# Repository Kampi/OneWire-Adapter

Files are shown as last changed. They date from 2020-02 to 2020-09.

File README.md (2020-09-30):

# 1-Wire Adapter

## Table of Contents

- [1-Wire Adapter](#1-wire-adapter)
  - [Table of Contents](#table-of-contents)
  - [About](#about)
  - [History](#history)
  - [Maintainer](#maintainer)

## About

Small extension board to use a UART as a 1-Wire interface.

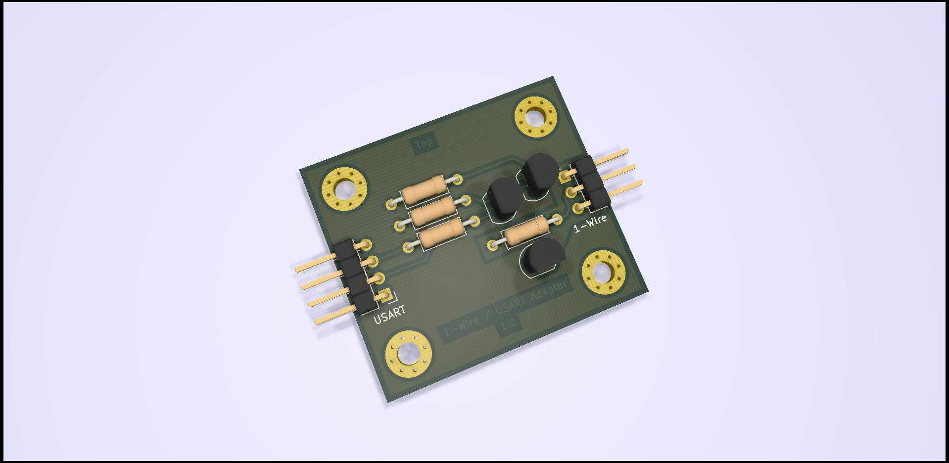
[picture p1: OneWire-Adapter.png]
Overview


## History

| **Version**  | **Description** | **Date** |
|:---:|:---:|:---:|
| 1.0 | First hardware release | 30.09.2020 |

## Maintainer

- [Daniel Kampert](mailto:DanielKampert@kampis-elektroecke.de)

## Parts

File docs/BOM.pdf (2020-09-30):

## Stückliste Bill of Materials

Nummer Number | Bezeichnung Description | Wert Value | Gehäuse Case | Hersteller Manufacturer | Herstellerbezeichnung Manufacturer's designation | Lieferant Distributor | Bestellnummer Order number | Anzahl Quantity
R1, R4 | Resistor | 10k | R_Axial_DIN0207_L6.3mm_D 2.5mm_P10.16mm_Horizont | Yageo | MFR-25FBF52-10K | | | 2
R2 | Resistor | 100k | R_Axial_DIN0207_L6.3mm_D 2.5mm_P10.16mm_Horizont | Yageo | MFR-25FBF52-100K | | | 1
R3 | Resistor | 4,7k | R_Axial_DIN0207_L6.3mm_D 2.5mm_P10.16mm_Horizont | Yageo | MFR-25FBF52-4K7 | | | 1
T1, T2 | 0.1A Ic, 45V Vce, Small Signal NPN Transistor, TO-92 | BC547 | TO-92_Inline | ON Semiconductor / Fairchild | BC547ATA | | | 2
T3 | 0.5A Id, 60V Vds, N-Channel MOSFET, TO-92 | BS170 | TO-92_Inline | ON Semiconductor / Fairchild | BS170 | | | 1
X1 | Generic connector, single row, 01x04 | USART | PinHeader_1x04_P2.54mm_ Horizontal | Harwin | M20-9960445 | | | 1
X2 | Generic connector, single row, 01x03 | 1-Wire | PinHeader_1x03_P2.54mm_ Horizontal | Harwin | M20-9750346 | | | 1

Legende / Legend:

Nicht bestückt | Not assembled
Durchsteckmontage | Through-Hole technology

30.09.2020

1.00

Bezeichnung / Name : 1-Wire / USART Adapter

Seite 1 von 2

## Technische Spezifikationen Technical Specifications

30.09.2020

1.00

Bezeichnung Description | Spezifikation Specification
Abmaße Dimensions | 40 x 35 mm
Standard Standard | IPC-A-610 E Class 2 oder höher IPC-A-610 E Class 2 or higher
Basismaterial Base material | 1,5 mm FR4, 35 µmCu
Stopplack Soldermask | Beidseitig Grün Both sides green
Bestückungsdruck Silkscreen | Keiner None
Oberfläche Surface | Chemisch Nickel-Gold Chemical nickel-gold
Isolierlack Insulation varnish | Nein No
Min. Bohrdurchmesser Min. drill-end diameter | 0,2 mm
Min. Leiterbahnbreite Min track size | 0,1 mm
Min. Leiterbahnabstand Min track distance | 0,2 mm
Kantenmetallisierung Sideplating | Nein No
Freistellung Vias Clearance vias | Bohrlochdurchmesser + max. 0,15 mm gemäß ZVEI Drill hole + max. 0,15 mm regarding ZVEI
Kontur Contour | Gefräst oder geritzt gemäß DIN ISO 2768 mittel Milled or scored according DIN ISO 2768 medium

Bezeichnung / Name: 1-Wire / USART Adapter

2 / 2

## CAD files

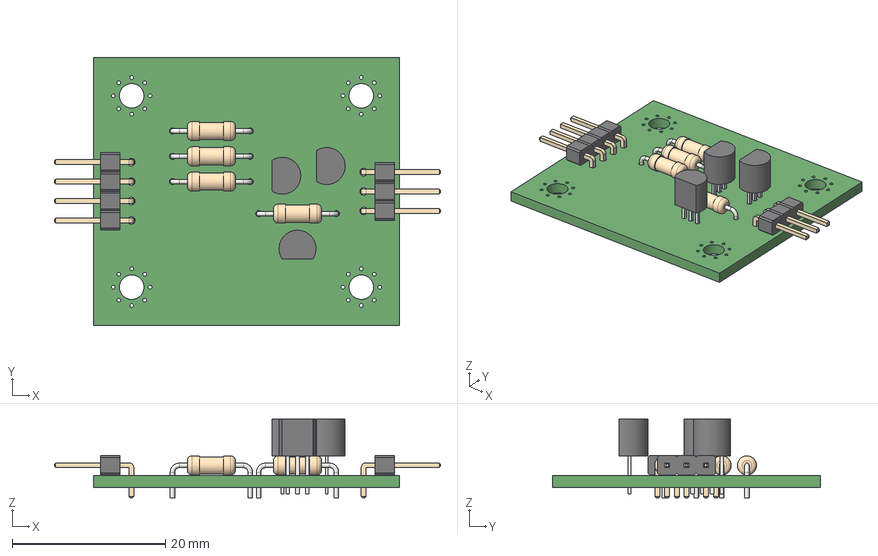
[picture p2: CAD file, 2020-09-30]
drawings/OneWire_Adapter.step
50.4 x 35.0 x 10.3 mm

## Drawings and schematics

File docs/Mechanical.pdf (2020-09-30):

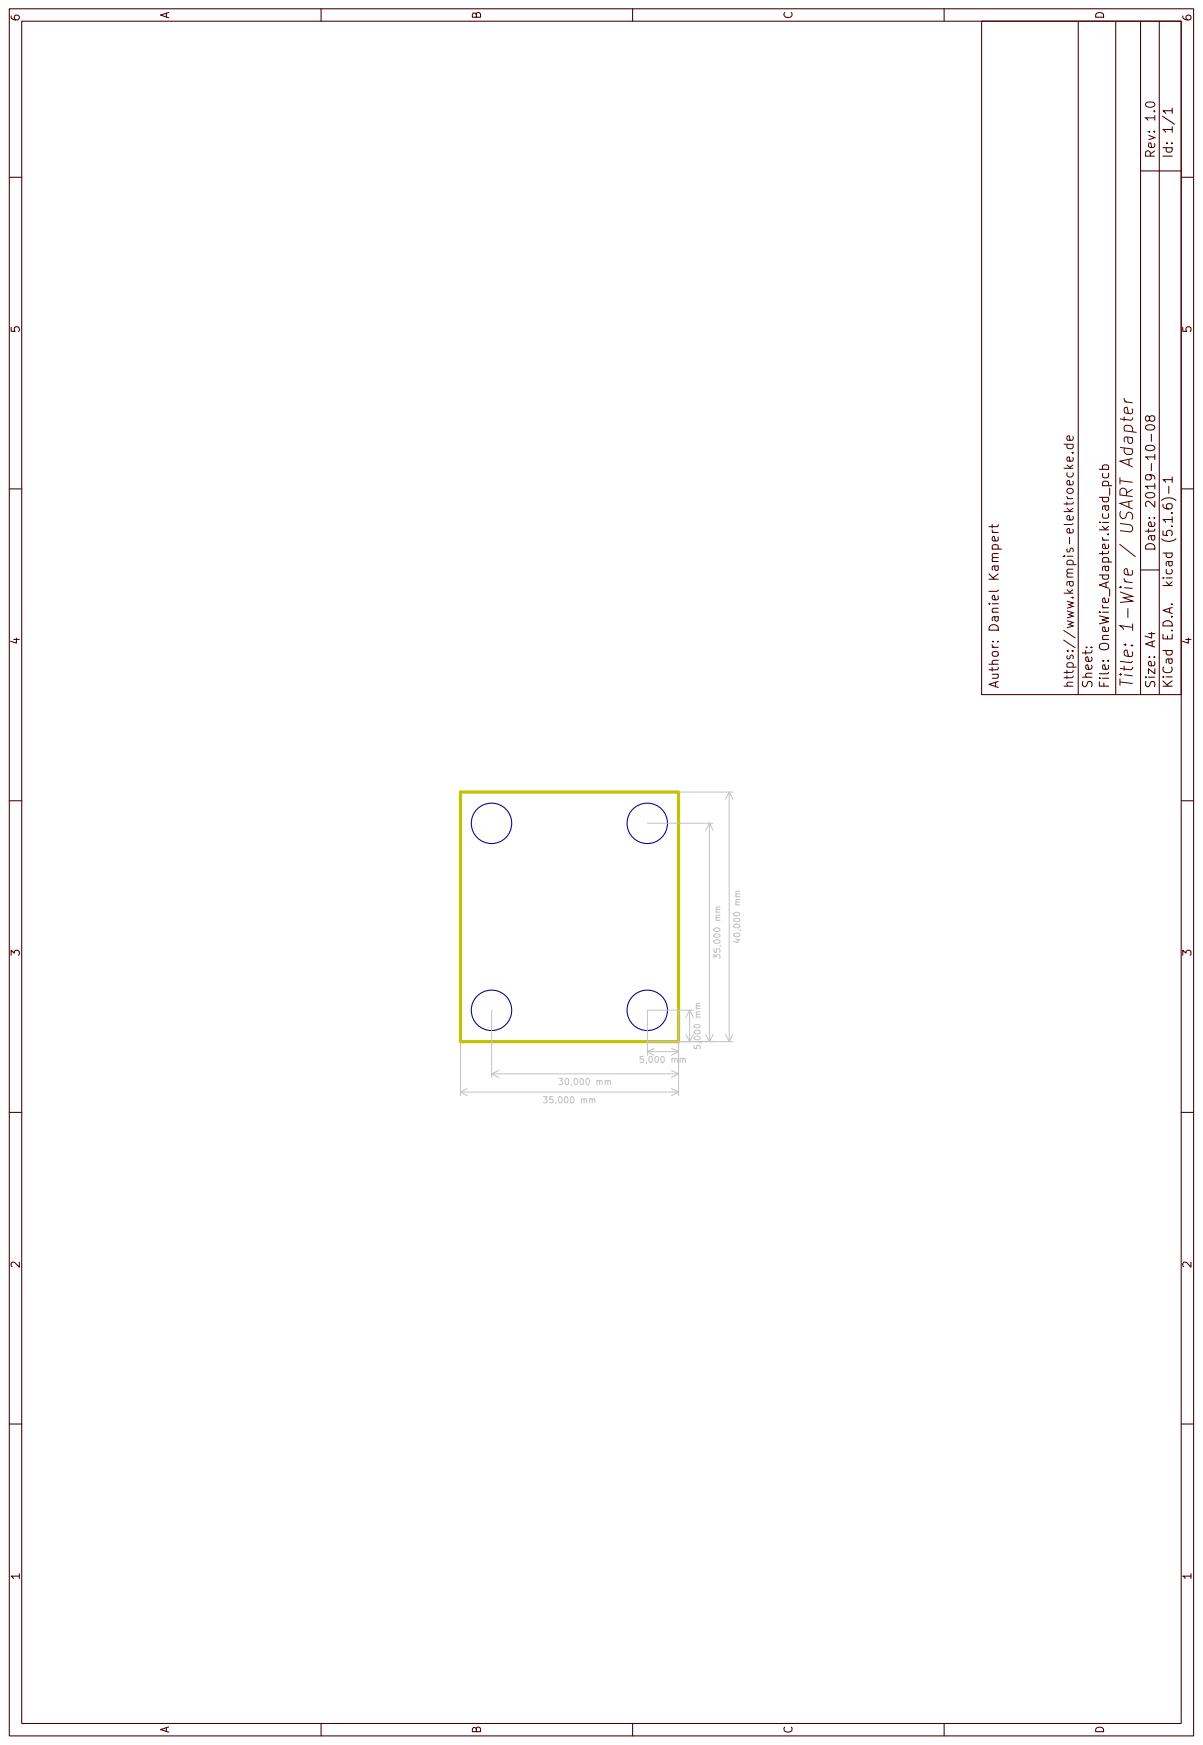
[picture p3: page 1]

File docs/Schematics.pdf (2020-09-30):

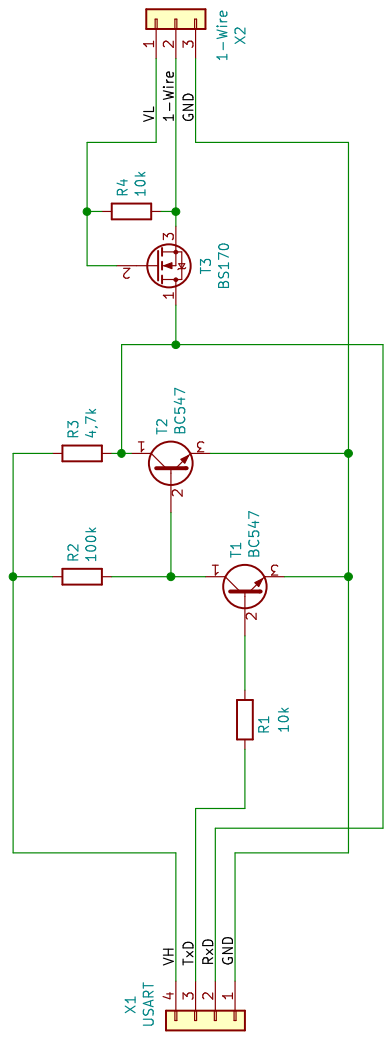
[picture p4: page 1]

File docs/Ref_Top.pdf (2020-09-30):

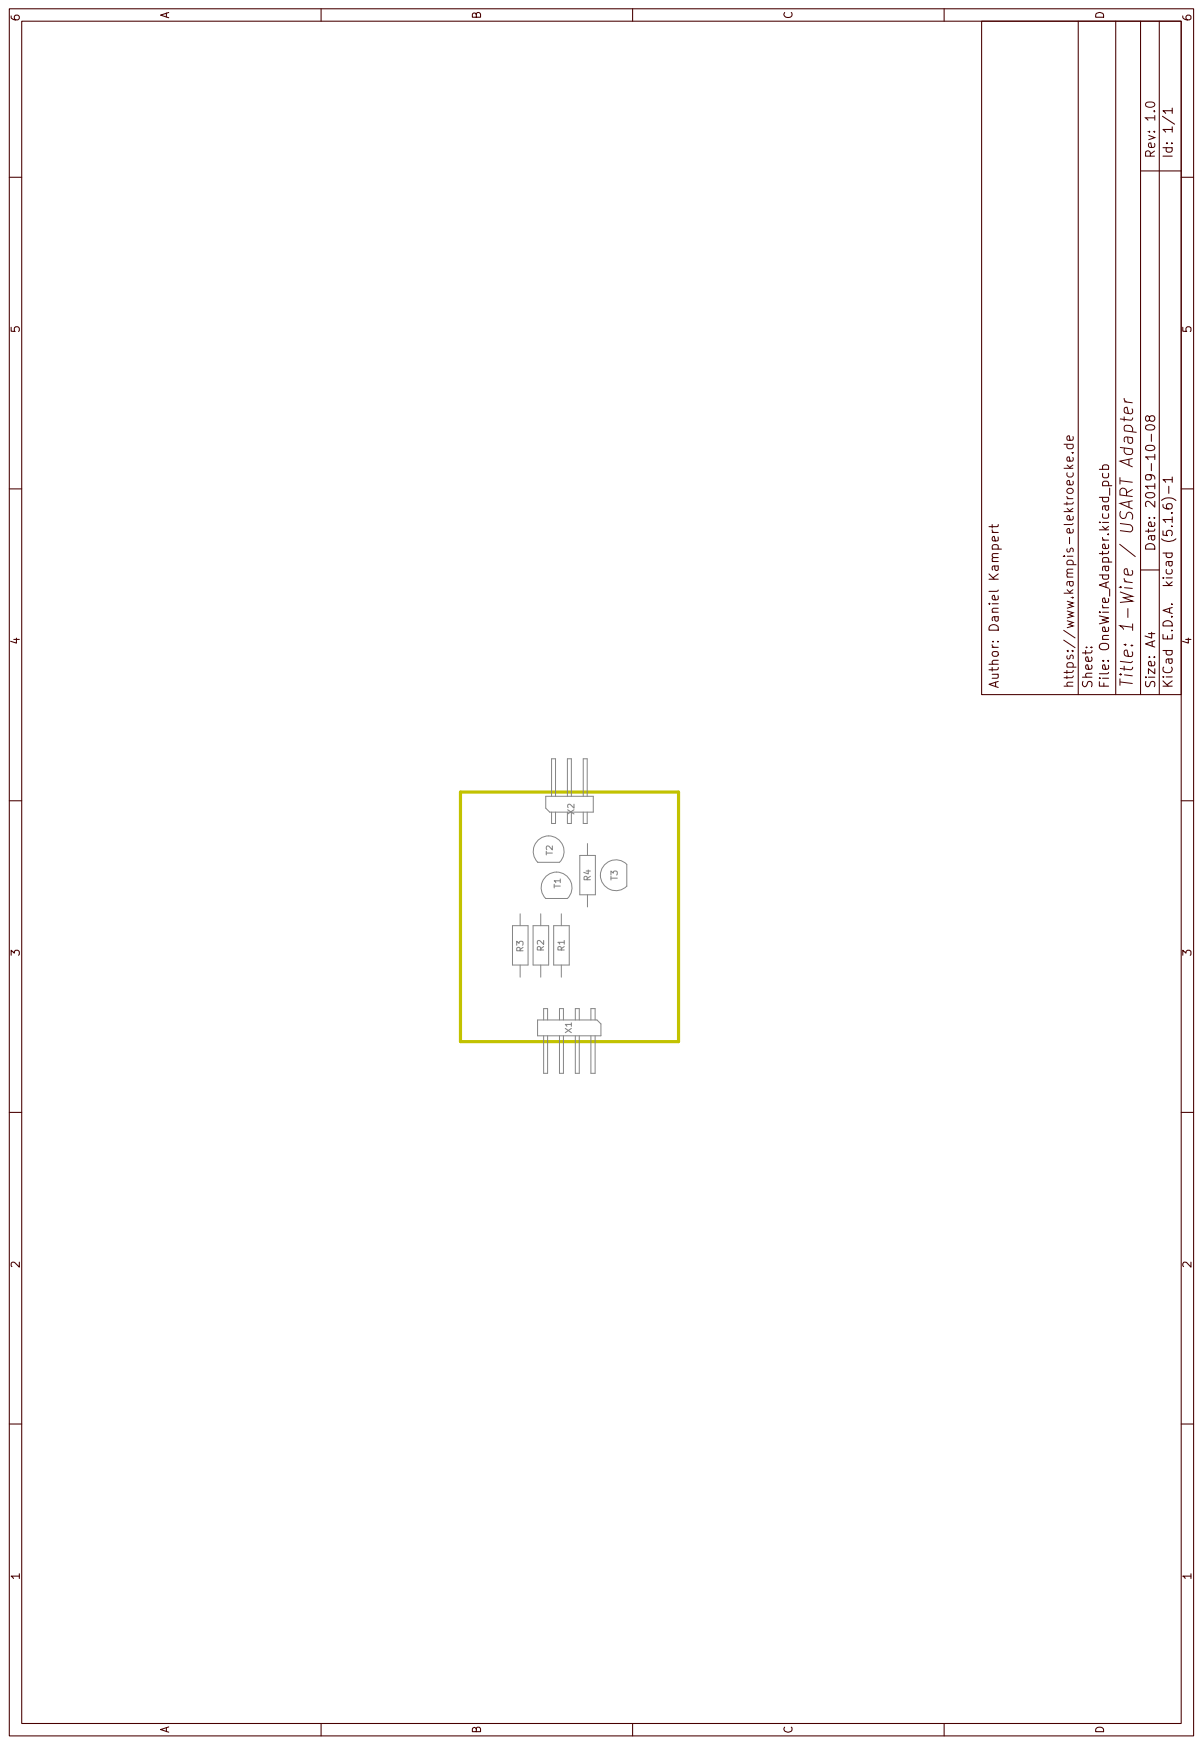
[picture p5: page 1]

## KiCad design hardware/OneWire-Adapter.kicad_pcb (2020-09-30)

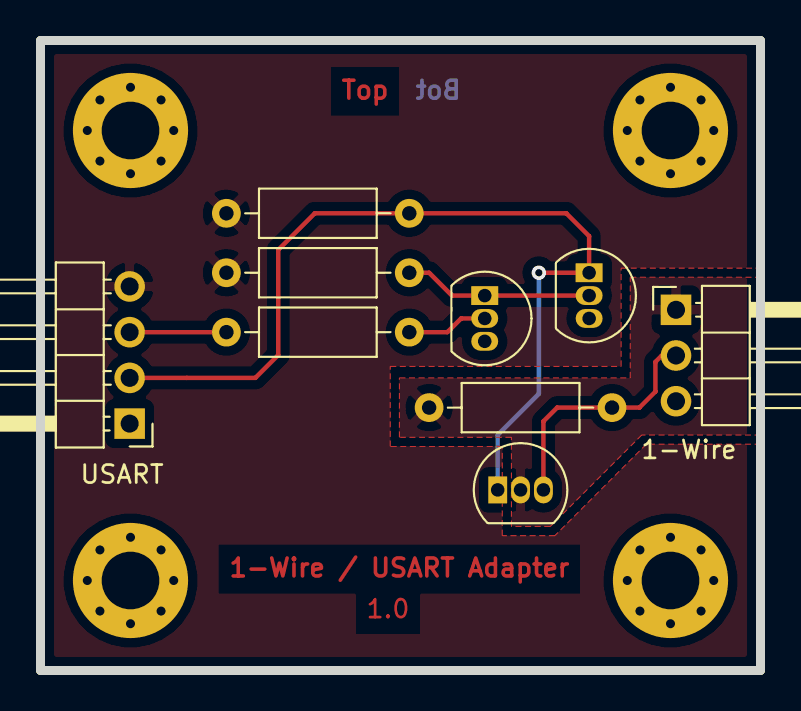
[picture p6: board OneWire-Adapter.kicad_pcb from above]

Board: 2 copper layers, 40.0 x 35.0 mm, 9 parts (0 on the bottom side), 8 nets.

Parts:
R1, R4: 10k; R_Axial_DIN0207_L6.3mm_D2.5mm_P10.16mm_Horizontal
R2: 100k; R_Axial_DIN0207_L6.3mm_D2.5mm_P10.16mm_Horizontal
R3: 4,7k; R_Axial_DIN0207_L6.3mm_D2.5mm_P10.16mm_Horizontal
T1, T2: BC547; TO-92_Inline
T3: BS170; TO-92_Inline
X1: USART; PinHeader_1x04_P2.54mm_Horizontal
X2: 1-Wire; PinHeader_1x03_P2.54mm_Horizontal

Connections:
/1-Wire: R4.2, T3.3, X2.2
/GND: T1.3, T2.3, X1.1, X2.3
/RxD: R3.2, T2.1, T3.1, X1.2
/TxD: R1.1, X1.3
/VH: R2.1, R3.1, X1.4
/VL: R4.1, T3.2, X2.1
unnamed: R1.2, T1.2
unnamed: R2.2, T1.1, T2.2

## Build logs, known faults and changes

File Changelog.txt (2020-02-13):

Verion					Comment
1.0					Initial release

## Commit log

2020-01-29 First hardware version
    [OneWire_Adapter-B_Cu.gbr, OneWire_Adapter-B_Mask.gbr, OneWire_Adapter-B_Paste.gbr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]
2020-01-29 Add level shifter
    [OneWire_Adapter-B_Cu.gbr, OneWire_Adapter-B_Mask.gbr, OneWire_Adapter-B_Paste.gbr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]
2020-01-30 Add production files
    [OneWire_Adapter-B_Cu.gbr, OneWire_Adapter-B_Mask.gbr, OneWire_Adapter-B_Paste.gbr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]
2020-01-30 Add new schematics
    [OneWire_Adapter.kicad_pcb, OneWire_Adapter.sch]
2020-09-30 Update project directory
    [BOM.xlsx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]
2020-09-30 Rename project
    [OneWire-Adapter.kicad_pcb, OneWire-Adapter.sch]
